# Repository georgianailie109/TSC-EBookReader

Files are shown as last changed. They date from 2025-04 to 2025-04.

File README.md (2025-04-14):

# TSC-EBookReader

## 1. Introducere si scop

OpenBook este un dispozitiv avansat construit in jurul microcontrolerului ESP32-C6, avand mai multi senzori si interfete. Acest dispozitiv este conceput pentru a oferi o experienta de citire electronica eficienta, cu un consum redus de energie si multiple functionalitati.

---

## 2. Diagrama bloc

```
        +------------------+
        |     Baterie      |
        +--------+---------+
                 |
                 v
        +--------------------+
        | Circuit Incarcare  |
        +--------+-----------+
                 |
                 v
        +--------------------+
        |        LDO         |
        +--------+-----------+
                 |
+----------------+---------------------------+
|                |           |              |
v                v           v              v
+--------+   +-----------+  +-----------+  +----------------+
| ESP32  |<->|  Display  |<->|  BME688  |<->| Butoane tactile|
|  -C6   |   | (SPI 4W)  |   | (I2C)    |   |   (GPIO + RC)  |
+--------+   +-----------+  +-----------+  +----------------+
     |             ^            ^                ^
     |             |            |                |
     v             |      Rezistente        Circuit RC
+-----------------------+  Pull-up         debounce
|     Conector USB-C    |
+-----------------------+
```

---

## 3. Imagini

Cateva imagini din proiect (plasate in folderul `Images/`):
exploded_view













---

## 4. BOM (Bill of Materials)

| Componenta | Link achizitie | Link datasheet |
|---|---|---|
| 112A-TAAR-R03 ATTEND | https://store.comet.srl.ro/Catalogue/Product/43497/ | https://www.snapeda.com/parts/112A-TAAR-R03/Attend/datasheet/ |
| BD5229G-TR | https://www.digikey.com/en/products/detail/rohm-semiconductor/BD5229G-TR/3663792 | https://fscdn.rohm.com/en/products/databook/datasheet/ic/power/voltage_detector/bd52xxg-e.pdf |
| ESP32 WROVER BME680 Sensor | https://store.comet.srl.ro/Catalogue/Product/50164/ | https://www.bosch-sensortec.com/media/boschsensortec/downloads/datasheets/bst-bme680-ds001.pdf |
| LED CHG_LED | https://ro.mouser.com/ProductDetail/Kingbright/KP-1608SURCK?qs=2JU0tDl2GZ3FuyEWfBV1%2Fg== | https://www.snapeda.com/parts/KP-1608SURCK/Kingbright/datasheet/ |
| Condensator C0402 | https://ro.mouser.com/c/passive-components/capacitors/ceramic-capacitors/?q=CC0402 | https://componentsearchengine.com/Datasheets/2/CC0402MRX5R5BB106.pdf |
| Condensator Tant | https://ro.mouser.com/ProductDetail/KYOCERA-AVX/TAJW107M010RNJ?qs=Wtp%252Bf%2FAeVqIH8v1VxV%252B1Rg%3D%3D | https://ro.mouser.com/datasheet/2/40/TAJ-3165264.pdf |
| Q1 DMG2305UX-7 | https://www.digikey.com/en/products/detail/diodes-incorporated/DMG2305UX-7/4340666 | https://www.diodes.com/assets/Datasheets/DMG2305UX.pdf |
| RTC MODULE DS3231SN# | https://www.snapeda.com/parts/DS3231SN%23/Analog+Devices/view-part/?ref=eda | https://www.snapeda.com/parts/DS3231SN%23/Analog%20Devices/datasheet/ |
| ESP32 C6 WROOM-1-N8 | https://ro.mouser.com/ProductDetail/Espressif-Systems/ESP32-C6-WROOM-1-N8?qs=8Wlm6%252BaMh8ST02Gmwp74cw%3D%3D | https://www.snapeda.com/parts/ESP32-C6-WROOM-1-N8/Espressif%20Systems/datasheet/ |
| FH34SRJ-24S-0.5SH(99) | https://ro.mouser.com/ProductDetail/Hirose-Connector/FH34SRJ-24S-0.5SH99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 | https://www.snapeda.com/parts/FH34SRJ-24S-0.5SH(99)/Hirose%20Connector/datasheet/ |
| MAX 17048G+T10 | https://www.snapeda.com/parts/MAX17048G+T10/Analog+Devices/view-part/?ref=eda | https://www.snapeda.com/parts/MAX17048G+T10/Analog%20Devices/datasheet/ |
| MBR0530 Schottky Diode | https://www.snapeda.com/parts/MBR0530/Onsemi/view-part/?ref=snap | https://www.snapeda.com/parts/MBR0530/ON%20Semiconductor/datasheet/ |
| MCP73831 Power Management | https://www.snapeda.com/parts/MCP73831T-2ACI/OT/Microchip/datasheet/ | https://www.snapeda.com/parts/MCP73831T-2ACI/OT/Microchip/datasheet/ |
| PFMF.050.1 | https://ro.mouser.com/ProductDetail/EPCOS-TDK/B72520T0350K062?qs=dEfas%2FXlABIszF52uu7vrg%3D%3D | https://www.tdk-electronics.tdk.com/inf/75/db/CTVS_14/Surge_protection_series.pdf |
| PGB1010603MR | https://www.snapeda.com/parts/PGB1010603MR/Littelfuse/view-part/?ref=eda | https://www.snapeda.com/parts/PGB1010603MR/Littelfuse%20Inc./datasheet/ |
| QWIIC_RIGHT_ANGLE CONNECTOR | https://ro.mouser.com/ProductDetail/SparkFun/PRT-14417?qs=wd5RIQLrsJhgdz%2FpmZ%2F3GQ== | https://ro.mouser.com/datasheet/2/813/Qwiic_Connector_Datasheet-1223982.pdf |
| Rezistenta R0402 | https://grabcad.com/library/resistor-0402-1) | https://www.yageo.com/upload/media/product/products/datasheet/rchip/PYu-RC_Group_51_RoHS_L_12.pdf |
| SD0805S020S1R0 | https://ro.mouser.com/ProductDetail/KYOCERA-AVX/SD0805S020S1R0?qs=jCA%252BPfw4LHbpkAoSnwrdjw%3D%3D | https://ro.mouser.com/datasheet/2/40/schottky-3165252.pdf |
| Si1308EDL-T1-GE3 MOSFET | https://www.snapeda.com/parts/SI1308EDL-T1-GE3/Vishay+Siliconix/view-part/?welcome=home&ref=eda | https://www.snapeda.com/parts/SI1308EDL-T1-GE3/Vishay%20Siliconix/datasheet/ |
| USB4110-GF-A | https://ro.mouser.com/ProductDetail/GCT/USB4110-GF-A?qs=KUoIvG%2F9IlYiZvIXQjyJeA%3D%3D | https://ro.mouser.com/datasheet/2/837/GCT_USB4110_Product_Drawing___20k_cycles-3455479.pdf |
| USBLC6-2SC6Y | https://ro.mouser.com/ProductDetail/STMicroelectronics/USBLC6-2SC6Y?qs=gNDSiZmRJS%2FOgDexvXkdow%3D%3D | https://ro.mouser.com/datasheet/2/389/usblc6_2sc6y-1852505.pdf |
| W25Q512JVEIQ | https://www.snapeda.com/parts/W25Q512JVEIQ/Winbond+Electronics/view-part/?ref=eda | https://www.winbond.com/resource-files/W25Q512JV%20SPI%20RevB%2006252019%20KMS.pdf |
| XC6220A331MR-G | https://componentsearchengine.com/part-view/XC6220A331MR-G/Torex | https://product.torexsemi.com/system/files/series/xc6220.pdf |
| 744043680 BOBINA | https://ro.mouser.com/ProductDetail/Wurth-Elektronik/744043680?qs=PGXP4M47uW6VkZq%252BkzjrHA%3D%3D | https://www.we-online.com/components/products/datasheet/744043680.pdf |

---

## 5. Functionalitatea hardware

- ESP32-C6 este componenta principala a proiectului OpenBook, oferind conectivitate Wi-Fi 6 si Bluetooth 5.0 LE. Datorita conectivitatii wireless integrate si a numarului mare de pini GPIO, microcontrollerul permite interfatarea cu diverse componente periferice, asigurand flexibilitate si performanta ridicata.
- Afisajul e-paper este conectat la ESP32-C6 prin interfata SPI si utilizeaza driver-ul BD5229G-TR pentru a gestiona tensiunile necesare functionarii. Alimentarea afisajului este controlata prin MOSFET-uri, permitand oprirea completa a acestuia atunci cand nu este utilizat, ceea ce contribuie la eficienta energetica a dispozitivului.
- Pentru monitorizarea conditiilor de mediu, proiectul utilizeaza senzorul BME688, capabil sa masoare temperatura, umiditatea, presiunea si calitatea aerului (VOC). Acesta comunica cu ESP32-C6 prin intermediul interfetei I2C si functioneaza la o tensiune de 3.3V, oferind date precise.
- Gestionarea energiei este realizata printr-un circuit de incarcare bazat pe MCP73831, care permite incarcarea bateriei cu un curent de pana la 500mA.
- Starea bateriei este monitorizata cu modulul MAX17048G+T10, care comunica prin aceeasi interfata I2C si furnizeaza informatii detaliate despre nivelul de incarcare si starea bateriei.

---

## 6. Alocarea pinilor ESP32-C6

| Componenta | Pini ESP32 | Interfata | Observatii |
|---|---|---|---|
| Afisaj E-Paper | IO12, IO11, IO5, IO4 | SPI | Control si resetare afisaj |
| Senzor BME688 | IO8, IO10 | I2C | Date de mediu (temperatura, umiditate) |
| Card SD | IO7 | SPI | Stocare externa |
| Modul RTC | IO8, IO10 | I2C | Ceas in timp real, partajeaza I2C |
| Serial USB | IO16, IO17 | UART | Programare si depanare |

---

## 7. Pasi de implementare

Proiectarea schemei electrice si conectarea componentelor la ESP32-C6
Realizarea layout-ului 2D si pozitionarea componentelor pe PCB
Rutarea traseelor pentru semnal si alimentare
Crearea planurilor de masa pe ambele straturi
Aplicarea regulilor pentru latimea traseelor si clearance
Pozitionarea strategica a conectorilor (ex: Qwiic, USB-C)
Adaugarea pad-urilor de test pentru depanare
Generarea modelului 3D si verificarea compatibilitatii mecanice

---

## 8. Informatii suplimentare relevante

- TP-urile au fost plasate in mod optim langa marginile placii si in apropierea componentelor esentiale pentru a permite acces facil la depanare si testare.
- Pentru diodele montate pe suprafata, dimensiunea initiala a pad-urilor era prea mica, ceea ce putea crea probleme la lipire. Dimensiunea a fost ajustata pentru a asigura o conexiune electrica fiabila si o asamblare mai usoara.
- Rutarea traseelor a fost realizata pe ambele straturi ale PCB-ului (superior si inferior), asigurand o distributie eficienta a semnalelor si a alimentarii.
- Planul de masa (GND) a fost aplicat pe ambele straturi pentru a optimiza performanta electrica.

---

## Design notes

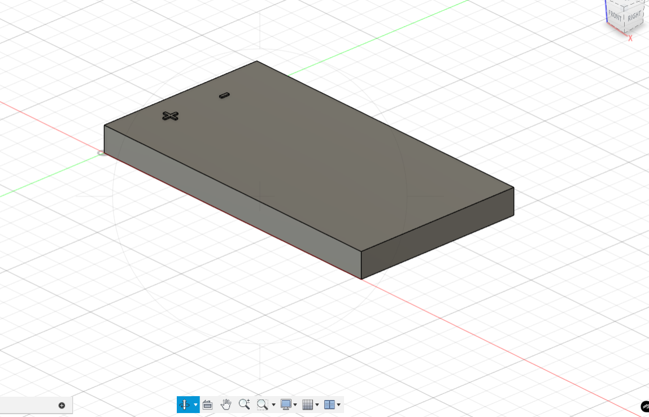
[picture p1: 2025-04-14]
Images/Screenshot 2025-04-14 140932.png

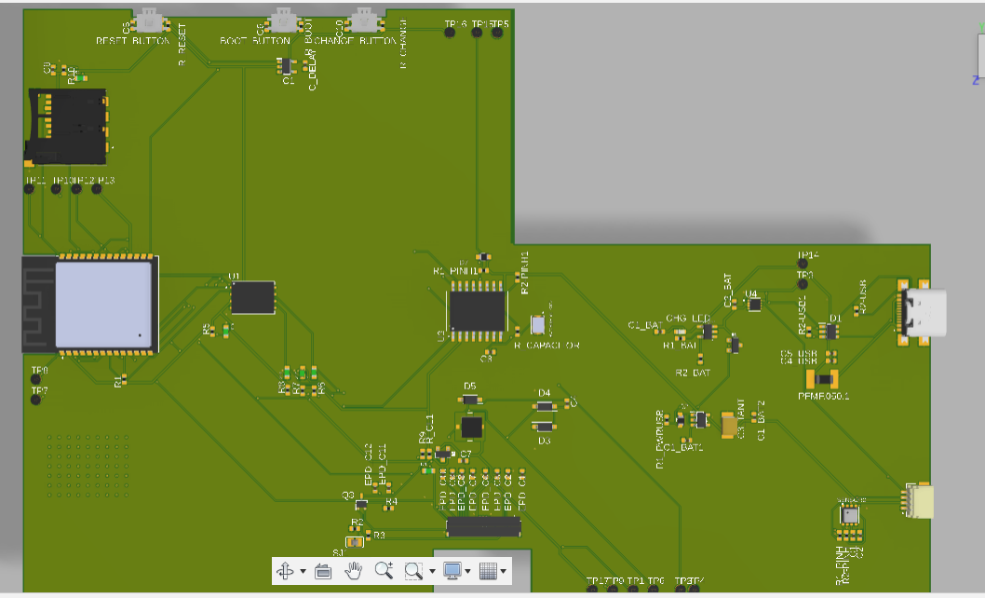
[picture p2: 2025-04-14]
Images/Screenshot 2025-04-14 141032.png

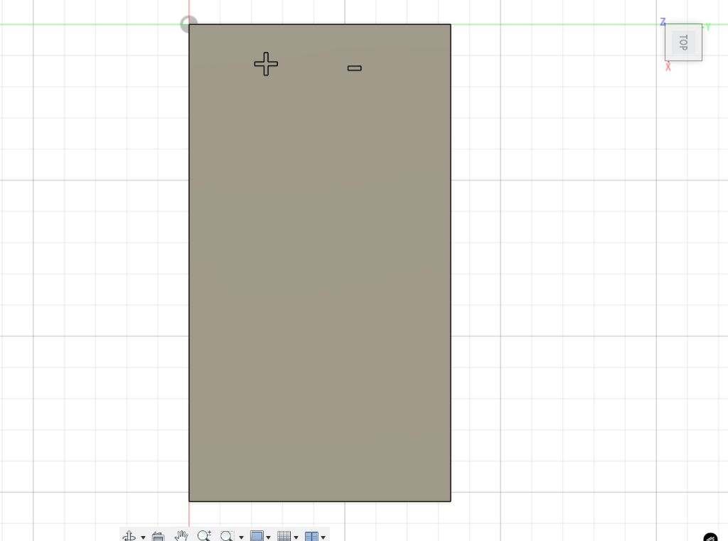
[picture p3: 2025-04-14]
Images/Screenshot 2025-04-14 140912.png

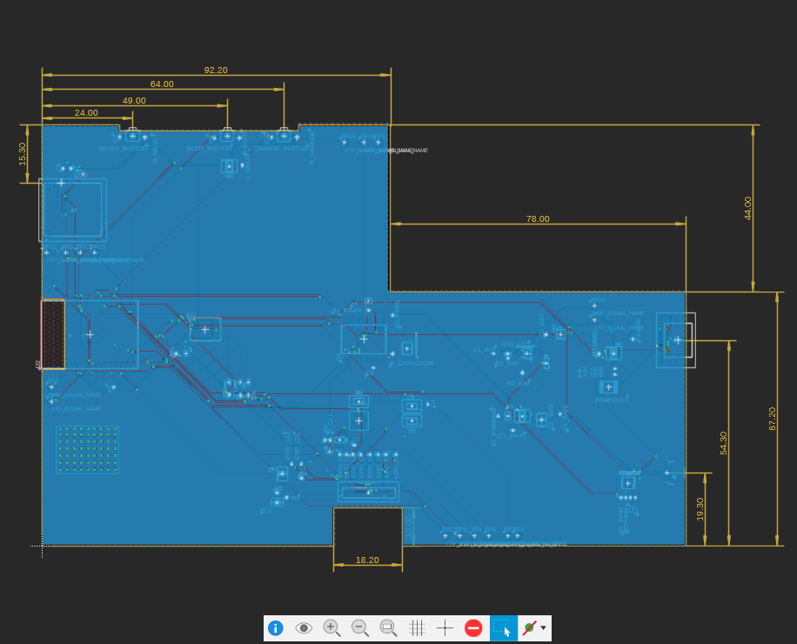
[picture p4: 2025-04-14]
Images/Screenshot 2025-04-14 141126.png

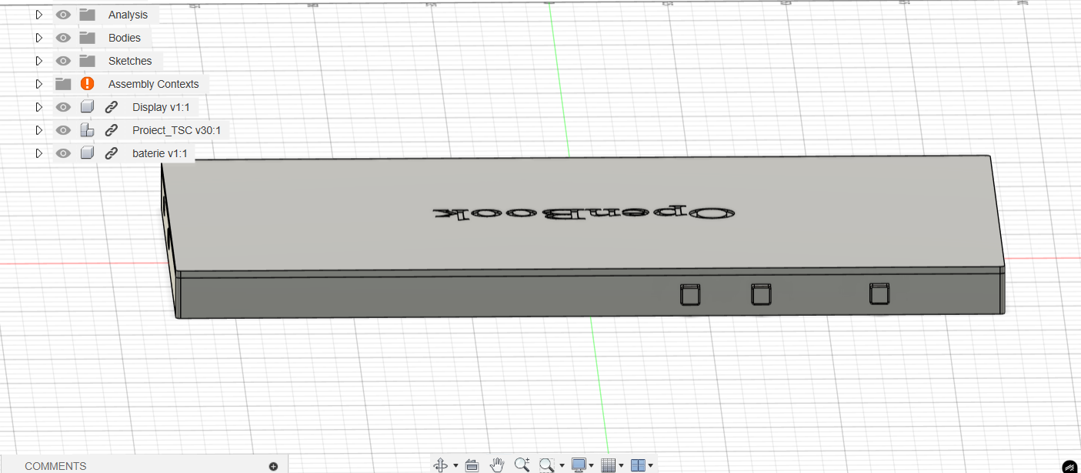
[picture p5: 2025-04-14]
Images/Screenshot 2025-04-14 140544.png

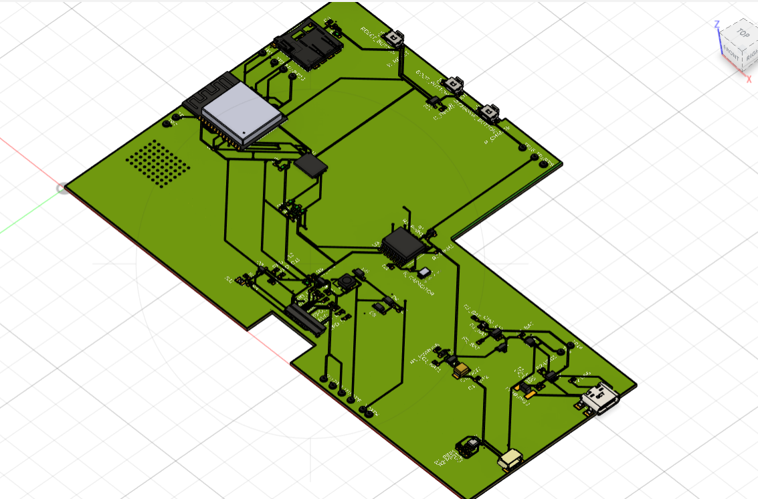
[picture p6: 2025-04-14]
Images/Screenshot 2025-04-14 141807.png

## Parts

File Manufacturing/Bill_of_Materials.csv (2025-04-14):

Qty | Value | Device | Package | Parts | Description | ARROW_PART_NUMBER | ARROW_PRICE-STOCK | AVAILABILITY | CENTROID_NOT_SPECIFIED | CHECK_PRICES | COPYRIGHT | DATASHEET | DESCRIPTION | DIGIKEY_DESCRIPTION | DIGIKEY_PART_NUMBER | HEIGHT | LEAD_FREE | MANUFACTURER_NAME | MANUFACTURER_PART_NUMBER | MF | MFR_NAME | MOUSER_PART_NUMBER | MOUSER_PRICE-STOCK | MOUSER_TESTING_PART_NUMBER | MOUSER_TESTING_PRICE-STOCK | MP | MPN | PACKAGE | POPULARITY | PREFIX | PRICE | PROD_ID | PURCHASE-URL | ROHS | SNAPEDA_LINK | SPICEMODEL | SPICEPREFIX | TEMPERATURE_RANGE_HIGH | TEMPERATURE_RANGE_LOW | VALUE
1 |  | ADAFRUIT_LEDCHIP-LED0603 | ADAFRUIT_CHIP-LED0603 | CHG_LED | LED
1 |  | SJ | SJ | SJ1 | SMD solder JUMPER |  |  |  |  |  |  |  |  |  |  |  |  |  |  |  |  |  |  |  |  |  |  |  | 3
1 | 0.1uF/50V | EAGLE-LTSPICE_CC0402 | EAGLE-LTSPICE_C0402 | EPD_C5 | CAPACITOR, European symbol
1 | 0.47 | ESP32_WROVER_EAGLE-LTSPICE_RR0402 | ESP32_WROVER_EAGLE-LTSPICE_R0402 | R3 | RESISTOR, European symbol
1 | 100 nF | ESP32_WROVER_EAGLE-LTSPICE_CC0402 | ESP32_WROVER_EAGLE-LTSPICE_C0402 | C4_USB | CAPACITOR, European symbol |  |  |  |  |  |  |  |  |  |  |  |  |  |  |  |  |  |  |  |  |  |  |  |  |  |  |  |  |  |  | NONE | C
1 | 100k | ESP32_WROVER_EAGLE-LTSPICE_RR0402 | ESP32_WROVER_EAGLE-LTSPICE_R0402 | R1_PWRUSB | RESISTOR, European symbol
7 | 100nF | EAGLE-LTSPICE_CC0402 | EAGLE-LTSPICE_C0402 | C1, C2, C6, C8, C9, C10, C_DELAY | CAPACITOR, European symbol
1 | 100uF | RCL_CPOL-EUCT3528 | RCL_CT3528 | C3_TANT | POLARIZED CAPACITOR, European symbol |  |  |  |  |  |  |  |  |  |  |  |  |  |  |  |  |  |  |  |  |  |  |  | 0 |  |  |  |  |  |  |  | C
10 | 10K | ESP32_WROVER_EAGLE-LTSPICE_RR0402 | ESP32_WROVER_EAGLE-LTSPICE_R0402 | R1_PINH, R1_PINH1, R2-PINH, R2-PINH1, R5, R6, R7, R8, R9, R10 | RESISTOR, European symbol
6 | 10k | ESP32_WROVER_EAGLE-LTSPICE_RR0402 | ESP32_WROVER_EAGLE-LTSPICE_R0402 | R1, R4, R_BOOT, R_CHANGE, R_CL1, R_RESET | RESISTOR, European symbol
1 | 10uF | EAGLE-LTSPICE_CC0402 | EAGLE-LTSPICE_C0402 | C7 | CAPACITOR, European symbol
1 | 112A-TAAR-R03_ATTEND | 112A-TAAR-R03_ATTEND | 112ATAARR03ATTEND | J4 | Micro SD Card Socket, Push-Push Type, Top Mount, SMT, H=1.83mm, 10u |  |  |  |  |  |  |  | Micro SD Card Socket | Push-Push Type | Top Mount | SMT | H=1.83mm | 10u |  |  | 1.9mm |  | ATTEND | 112A-TAAR-R03 ATTEND
1 | 15 | ESP32_WROVER_EAGLE-LTSPICE_RR0402 | ESP32_WROVER_EAGLE-LTSPICE_R0402 | R_CAPACITOR | RESISTOR, European symbol
1 | 1uF | EAGLE-LTSPICE_CC0402 | EAGLE-LTSPICE_C0402 | C5 | CAPACITOR, European symbol
9 | 1uF/50V | EAGLE-LTSPICE_CC0402 | EAGLE-LTSPICE_C0402 | EPD_C1, EPD_C2, EPD_C6, EPD_C7, EPD_C8, EPD_C9, EPD_C10, EPD_C11, EPD_C12 | CAPACITOR, European symbol
1 | 2.2 | ESP32_WROVER_EAGLE-LTSPICE_RR0402 | ESP32_WROVER_EAGLE-LTSPICE_R0402 | R2 | RESISTOR, European symbol
1 | 200 | ESP32_WROVER_EAGLE-LTSPICE_RR0402 | ESP32_WROVER_EAGLE-LTSPICE_R0402 | R1_BAT | RESISTOR, European symbol
2 | 20V/4.2A/52mO/1.4W | ESP32_WROVER_SPARKFUN-DISCRETESEMI_MOSFET_PCH-DMG2305UX-7 | ESP32_WROVER_SPARKFUN-DISCRETESEMI_SOT23-3 | Q1, Q2 | P-channel MOSFETs |  |  |  |  |  |  |  |  |  |  |  |  |  |  |  |  |  |  |  |  |  |  |  |  |  |  | TRAN-14388 |  |  |  |  |  |  |  | 20V/4.2A/52mO/1.4W
1 | 2k | ESP32_WROVER_EAGLE-LTSPICE_RR0402 | ESP32_WROVER_EAGLE-LTSPICE_R0402 | R2_BAT | RESISTOR, European symbol
1 | 4.5uF | ESP32_WROVER_EAGLE-LTSPICE_CC0402 | ESP32_WROVER_EAGLE-LTSPICE_C0402 | C5_USB | CAPACITOR, European symbol |  |  |  |  |  |  |  |  |  |  |  |  |  |  |  |  |  |  |  |  |  |  |  |  |  |  |  |  |  |  | NONE | C
2 | 4.7uF | EAGLE-LTSPICE_CC0402 | EAGLE-LTSPICE_C0402 | C1_BAT, C2_BAT | CAPACITOR, European symbol
2 | 4.7uF | ESP32_WROVER_EAGLE-LTSPICE_CC0402 | ESP32_WROVER_EAGLE-LTSPICE_C0402 | C1_BAT1, C1_BAT2 | CAPACITOR, European symbol |  |  |  |  |  |  |  |  |  |  |  |  |  |  |  |  |  |  |  |  |  |  |  |  |  |  |  |  |  |  | NONE | C
1 | 4.7uF/25V | EAGLE-LTSPICE_CC0402 | EAGLE-LTSPICE_C0402 | C4 | CAPACITOR, European symbol
2 | 5k1 | ESP32_WROVER_EAGLE-LTSPICE_RR0402 | ESP32_WROVER_EAGLE-LTSPICE_R0402 | R2-USB, R2-USB1 | RESISTOR, European symbol
1 | 68uH | 744043680IND_4828-WE-TPC_WRE | IND_4828-WE-TPC_WRE | L1 |  |  |  |  |  |  | Copyright (C) 2024 Ultra Librarian. All rights reserved. |  |  |  |  |  |  |  | 744043680 |  | Wurth Electronics
1 | BD5229G-TR | BD5229G-TR | SOT95P280X125-5N | IC1 | Voltage Detector with Adjustable Delay Time: CMOS processes are utilized to develop high precision, low current consumption CMOS reset ICs that allow arbitrary setting of the delay time. The extensive lineup includes both Nch Open Drain and CMOS output types in a wide range of detection voltages (from 2.3V to 6.0V, in 0.1V steps), enabling selection of the ideal solution based on customer requirements. In addition, the entire series is of course both lead-free and RoHS-compliant. |  |  |  |  |  |  |  | Voltage Detector with Adjustable Delay Time: CMOS processes are utilized to develop high precision | low current consumption CMOS reset ICs that allow arbitrary setting of the delay time. The extensive lineup includes both Nch Open Drain and CMOS output types in a wide range of detection voltages (from 2.3V to 6.0V | in 0.1V steps) | enabling selection of the ideal solution based on customer requirements. In addition | the entire series is of course both lead-free and RoHS-compliant. |  |  | 1.25mm |  | ROHM Semiconductor | BD5229G-TR |  |  | 755-BD5229G-TR | https://www.mouser.co.uk/ProductDetail/ROHM-Semiconductor/BD5229G-TR?qs=4kLU8WoGk0vvnhrrYwdszw%3D%3D
3 | BUTTON_CUSYOMV1 | BUTTON_CUSYOMV1 | MYBUTTON | BOOT_BUTTON, CHANGE_BUTTON, RESET_BUTTON
1 | CPH3225A | CPH3225A | CAPCP3225X100N | C10_SUPERCAP | Cap 0.011F 3.3V 1210 Flat Check availability |  |  | Not in stock |  | https://www.snapeda.com/parts/CPH3225A/Seiko+Instruments/view-part/?ref=eda |  |  | 11 mF (EDLC) Supercapacitor 3.3 V 1210 (3225 Metric) - - |  |  |  |  |  |  | Seiko Instruments |  |  |  |  |  | CPH3225A |  | 1210 Seiko |  |  | None |  | https://www.snapeda.com/api/url_track_click_mouser/?unipart_id=562593&manufacturer=Seiko Instruments&part_name=CPH3225A&search_term=None |  | https://www.snapeda.com/parts/CPH3225A/Seiko+Instruments/view-part/?ref=snap
1 | DS3231SN# | DS3231SN# | SOIC127P1032X265-16N | U3 | Real Time Clock Serial 16-Pin SOIC W T/R Check availability |  |  | In Stock |  | https://www.snapeda.com/parts/DS3231SN%23/Analog+Devices/view-part/?ref=eda |  |  | Extremely Accurate I²C-Integrated RTC/TCXO/Crystal |  |  |  |  |  |  | Analog Devices |  |  |  |  |  | DS3231SN# |  | SOIC-16 Maxim |  |  | None |  | https://www.snapeda.com/api/url_track_click_mouser/?unipart_id=99048&manufacturer=Analog Devices&part_name=DS3231SN#&search_term=None |  | https://www.snapeda.com/parts/DS3231SN%23/Analog+Devices/view-part/?ref=snap
1 | ESP32-C6-WROOM-1-N8 | ESP32-C6-WROOM-1-N8 | XCVR_ESP32-C6-WROOM-1-N8 | U2 | Check availability |  |  | In Stock |  | https://www.snapeda.com/parts/ESP32-C6-WROOM-1-N8/Espressif+Systems/view-part/?ref=eda |  |  | Multiprotocol Modules ESP32-C6 module | Wi-Fi 6 in 2.4 GHz band | Bluetooth 5 | Zigbee 3.0 and Thread. ESP34-WROOM Compatible - ENGINEERING SAMPLE |  |  |  |  |  |  | Espressif Systems |  |  |  |  |  | ESP32-C6-WROOM-1-N8 |  | None |  |  | None |  |  |  | https://www.snapeda.com/parts/ESP32-C6-WROOM-1-N8/Espressif+Systems/view-part/?ref=snap
1 | ESP32C6_VARISTORCN1812 | ESP32C6_VARISTORCN1812 | ESP32C6_VARISTOR_CT/CN1812 | PFMF.050.1 | VARISTOR |  |  |  |  |  |  |  |  |  |  |  |  |  |  |  |  |  |  |  |  |  |  |  | 0
2 | ESP32_WROVER_AVX---SD0805S020S1R0_AVX_SD0805S020S1R0_0_0AVX_SD0805S020S1R0_0_0 | ESP32_WROVER_AVX---SD0805S020S1R0_AVX_SD0805S020S1R0_0_0AVX_SD0805S020S1R0_0_0 | ESP32_WROVER_AVX---SD0805S020S1R0_AVX_SD0805S020S1R0_0 | D2, D7 | Schottky Barrier Rectifier Diode |  |  |  | No |  |  | http://datasheets.avx.com/schottky.pdf |  | DIODE SCHOTTKY 20V 1A 0805 | 478-7800-1-ND |  | yes |  |  | AVX |  | 581-SD0805S020S1R0 |  |  |  |  |  | 0805 (2012 metric) |  | D |  |  |  | yes |  |  |  | +125°C | -55°C
1 | ESP32_WROVER_BME680_BME680 | ESP32_WROVER_BME680_BME680 | ESP32_WROVER_BME680_PSON80P300X300X100-8N | SENSOR2 | Integrated Environmental Unit |  |  | Unavailable |  |  |  |  | Integrated Environmental Unit |  |  |  |  |  |  | Bosch Sensortec |  |  |  |  |  | BME680 |  | LGA-8 Bosch Tools |  |  | None
1 | ESP32_WROVER_SPARKFUN-IC-POWER_MCP73831 | ESP32_WROVER_SPARKFUN-IC-POWER_MCP73831 | ESP32_WROVER_SPARKFUN-IC-POWER_SOT23-5 | MCP73831 | MCP73831T Li-Ion, Li-Pol Controller |  |  |  |  |  |  |  |  |  |  |  |  |  |  |  |  |  |  |  |  |  |  |  |  |  |  | IC-09995
1 | FH34SRJ-24S-0.5SH_99_ | FH34SRJ-24S-0.5SH_99_ | FH34SRJ24S05SH99 | J1 | (0.50mm) Surface Mount, Right Angle |  |  |  |  |  |  |  | 24 Position FFC | FPC Connector Contacts | (0.50mm) Surface Mount | Right Angle |  |  | 1.1mm |  | Hirose | FH34SRJ-24S-0.5SH(99) |  |  | 798-FH34SRJ24S05SH99 | https://www.mouser.co.uk/ProductDetail/Hirose-Connector/FH34SRJ-24S-0.5SH99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
1 | MAX17048G+T10 | MAX17048G+T10 | SON50P200X200X80-9N | U4 | Check availability |  |  | In Stock |  | https://www.snapeda.com/parts/MAX17048G+T10/Analog+Devices/view-part/?ref=eda |  |  | 3µA 1-Cell/2-Cell Fuel Gauge with ModelGauge |  |  |  |  |  |  | Analog Devices |  |  |  |  |  | MAX17048G+T10 |  | TDFN-8 Maxim |  |  | None |  | https://www.snapeda.com/api/url_track_click_mouser/?unipart_id=329239&manufacturer=Analog Devices&part_name=MAX17048G+T10&search_term=None |  | https://www.snapeda.com/parts/MAX17048G+T10/Analog+Devices/view-part/?ref=snap
3 | MBR0530 | MBR0530 | SOD3716X135N | D3, D4, D5 | ON SEMICONDUCTOR - MBR0530 - DIODE, SCHOTTKY, 0.5A, 30V, SOD-123 |  |  | In Stock |  | https://www.snapeda.com/parts/MBR0530/Onsemi/view-part/?ref=eda |  |  | Diode Schottky 30 V 500mA Surface Mount SOD-123 |  |  |  |  |  |  | ON Semiconductor |  |  |  |  |  | MBR0530 |  | SOD-123-2 ON Semiconductor |  |  | None |  | https://www.snapeda.com/api/url_track_click_mouser/?unipart_id=179458&manufacturer=ON Semiconductor&part_name=MBR0530&search_term=None |  | https://www.snapeda.com/parts/MBR0530/Onsemi/view-part/?ref=snap
6 | PGB1010603MR | PGB1010603MR | DIOC1608X36N | D6, D8, D9, D10, D11, D12 | Check availability |  |  | In Stock |  | https://www.snapeda.com/parts/PGB1010603MR/Littelfuse/view-part/?ref=eda |  |  | 150V (Typ) Clamp - Ipp Tvs Diode Surface Mount 0603 (1608 Metric) |  |  |  |  |  |  | Littelfuse Inc. |  |  |  |  |  | PGB1010603MR |  | 0603 Littelfuse Inc. |  |  | None |  | https://www.snapeda.com/api/url_track_click_mouser/?unipart_id=5659453&manufacturer=Littelfuse Inc.&part_name=PGB1010603MR&search_term=None |  | https://www.snapeda.com/parts/PGB1010603MR/Littelfuse/view-part/?ref=snap
1 | QWIIC_RIGHT_ANGLE | QWIIC_CONNECTORJS-1MM | JST04_1MM_RA | J3 | SparkFun I2C Standard Qwiic Connector |  |  |  |  |  |  |  |  |  |  |  |  |  |  |  |  |  |  |  |  |  |  |  |  |  |  | CONN-13694 |  |  |  |  |  |  |  | QWIIC_RIGHT_ANGLE
1 | SAMACSYS_PARTS_USB4110-GF-A | SAMACSYS_PARTS_USB4110-GF-A | SAMACSYS_PARTS_USB4110GFA | J2 | CONN USB 2.0 TYPE-C R/A SMT |  |  |  |  |  |  |  | CONN USB 2.0 TYPE-C R/A SMT |  |  | 3.26mm |  | GCT (GLOBAL CONNECTOR TECHNOLOGY) | USB4110-GF-A |  |  | 640-USB4110-GF-A | https://www.mouser.co.uk/ProductDetail/GCT/USB4110-GF-A?qs=KUoIvG%2F9IlYiZvIXQjyJeA%3D%3D
1 | SI1308EDL-T1-GE3 | SI1308EDL-T1-GE3 | SOT65P210X110-3N | Q3 | MOSFET N-Ch 30V 1.5A TrenchFET SC70 Vishay Si1308EDL-T1-GE3 N-channel MOSFET Transistor, 1.5 A, 30 V, 3-Pin SC-70 |  |  | In Stock |  | https://www.snapeda.com/parts/SI1308EDL-T1-GE3/Vishay+Siliconix/view-part/?ref=eda |  |  | Si1308EDL-T1-GE3 N-channel MOSFET Transistor | 1.5 A | 30 V | 3-Pin SC-70 | Siliconix / Vishay SI1308EDL-T1-GE3 |  |  |  |  |  |  | Vishay Siliconix |  |  |  |  |  | SI1308EDL-T1-GE3 |  | SOT-323 Vishay Semiconductor |  |  | None |  | https://www.snapeda.com/api/url_track_click_mouser/?unipart_id=274603&manufacturer=Vishay Siliconix&part_name=SI1308EDL-T1-GE3&search_term=None |  | https://www.snapeda.com/parts/SI1308EDL-T1-GE3/Vishay+Siliconix/view-part/?ref=snap
17 | TPTP20R | TPTP20R | TP20R | TP1, TP2, TP3, TP4, TP5, TP6, TP7, TP8, TP9, TP10, TP11, TP12, TP13, TP14, TP15, TP16, TP17 | Test pad
1 | USBLC6-2SC6Y | USBLC6-2SC6Y | SOT95P280X145-6N | D1 | Low Cap. ESD Protection Auto SOT-23-6 STMicroelectronics USBLC6-2SC6Y, Dual Uni-Directional TVS Diode Array, 6-Pin SOT-23 |  |  | In Stock |  | https://www.snapeda.com/parts/USBLC6-2SC6Y/STMicroelectronics/view-part/?ref=eda |  |  | 17V Clamp 5A (8/20µs) Ipp Tvs Diode Surface Mount SOT-23-6 |  |  |  |  |  |  | STMicroelectronics |  |  |  |  |  | USBLC6-2SC6Y |  | SOT-23-6 STMicroelectronics |  |  | None |  |  |  | https://www.snapeda.com/parts/USBLC6-2SC6Y/STMicroelectronics/view-part/?ref=snap
1 | W25Q512JVEIQ | W25Q512JVEIQ | SON127P600X800X80-9N | U1 | Check availability |  |  | In Stock |  | https://www.snapeda.com/parts/W25Q512JVEIQ/Winbond+Electronics/view-part/?ref=eda |  |  | FLASH - NOR Memory IC 512Mb (64M x 8) SPI - Quad I/O 133 MHz 8-WSON (8x6) |  |  |  |  |  |  | Winbond Electronics |  |  |  |  |  | W25Q512JVEIQ |  | Package |  |  | None |  |  |  | https://www.snapeda.com/parts/W25Q512JVEIQ/Winbond+Electronics/view-part/?ref=snap
1 | XC6220A331MR-G | XC6220A331MR-G | SOT95P280X120-5N | IC4 | LDO Voltage Regulators |  |  |  |  |  |  |  | LDO Voltage Regulators |  |  | 1.2mm |  | Torex | XC6220A331MR-G |  |  | 865-XC6220A331MR-G | https://www.mouser.co.uk/ProductDetail/Torex-Semiconductor/XC6220A331MR-G?qs=AsjdqWjXhJ8ZSWznL1J0gg%3D%3D

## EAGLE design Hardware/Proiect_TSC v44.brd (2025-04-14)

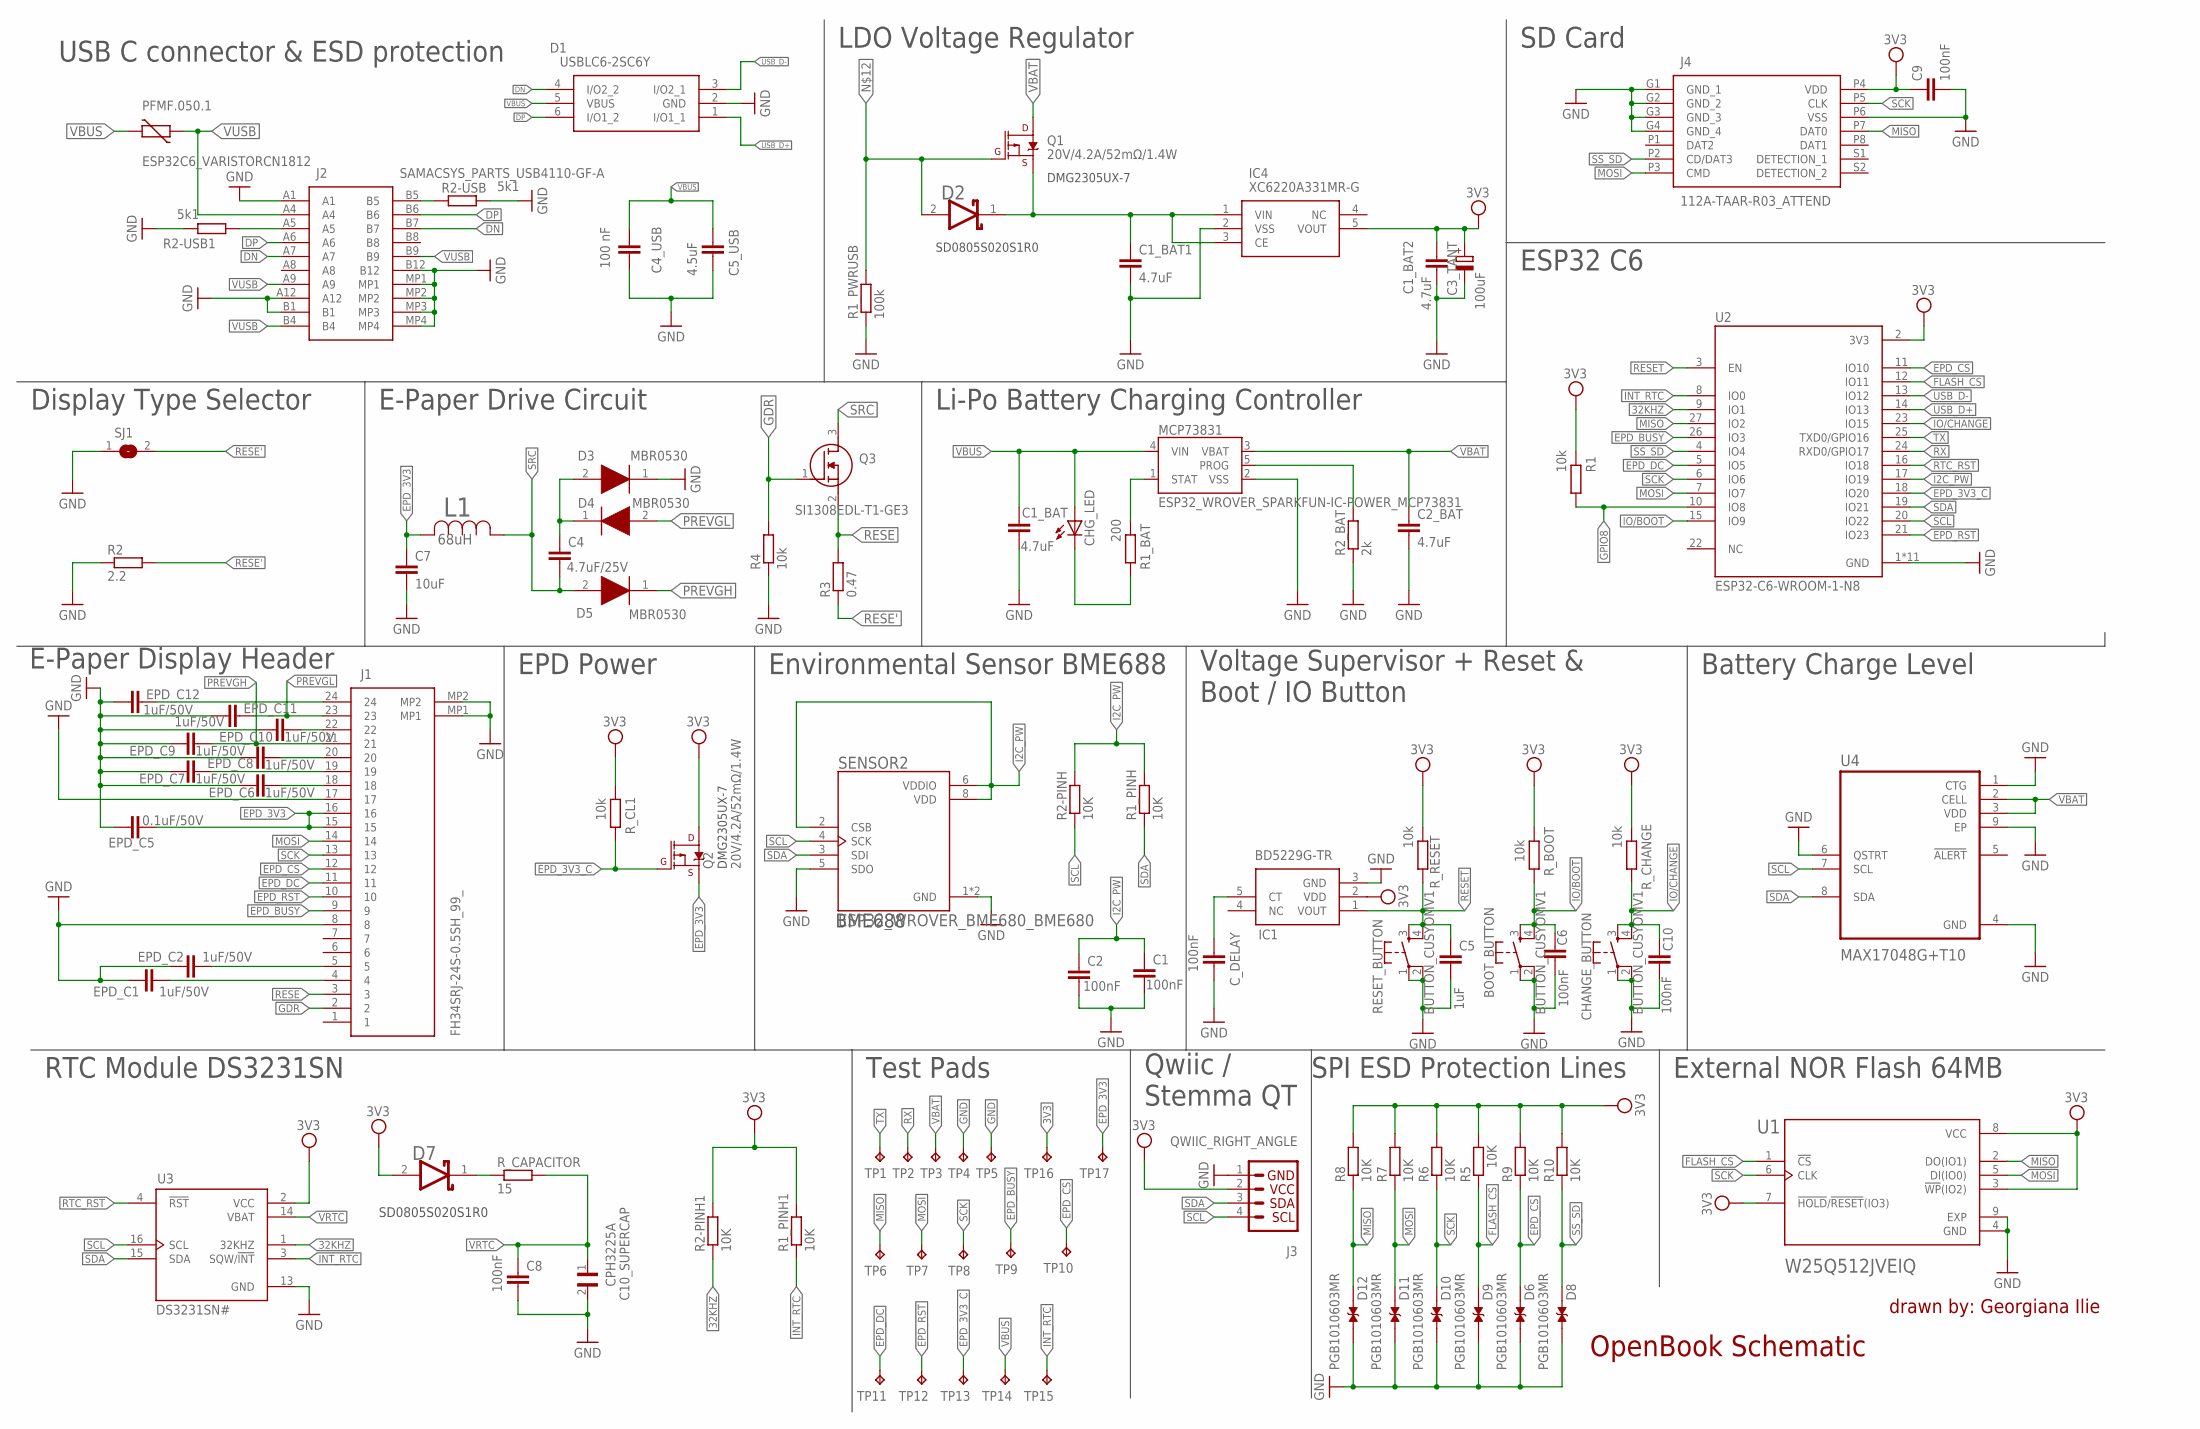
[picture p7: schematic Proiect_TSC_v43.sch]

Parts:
BOOT_BUTTON: BUTTON_CUSYOMV1; MYBUTTON
C1, C2, C6, C8, C9, C10: 100nF; EAGLE-LTSPICE_C0402
C1_BAT, C2_BAT: 4.7uF; EAGLE-LTSPICE_C0402
C1_BAT1, C1_BAT2: 4.7uF; ESP32_WROVER_EAGLE-LTSPICE_C0402
C3_TANT: 100uF; RCL_CT3528
C4: 4.7uF/25V; EAGLE-LTSPICE_C0402
C4_USB: 100 nF; ESP32_WROVER_EAGLE-LTSPICE_C0402
C5: 1uF; EAGLE-LTSPICE_C0402
C5_USB: 4.5uF; ESP32_WROVER_EAGLE-LTSPICE_C0402
C7: 10uF; EAGLE-LTSPICE_C0402
C10_SUPERCAP: CPH3225A; CAPCP3225X100N
CHANGE_BUTTON: BUTTON_CUSYOMV1; MYBUTTON
CHG_LED: ADAFRUIT_LEDCHIP-LED0603; ADAFRUIT_CHIP-LED0603
C_DELAY: 100nF; EAGLE-LTSPICE_C0402
D1: USBLC6-2SC6Y; SOT95P280X145-6N
D2, D7: ESP32_WROVER_AVX---SD0805S020S1R0_AVX_SD0805S020S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; ESP32_WROVER_AVX---SD0805S020S1R0_AVX_SD0805S020S1R0_0
D3, D4, D5: MBR0530; SOD3716X135N
D6, D8, D9, D10, D11, D12: PGB1010603MR; DIOC1608X36N
EPD_C1, EPD_C2, EPD_C6, EPD_C7, EPD_C8, EPD_C9, EPD_C10, EPD_C11, EPD_C12: 1uF/50V; EAGLE-LTSPICE_C0402
EPD_C5: 0.1uF/50V; EAGLE-LTSPICE_C0402
IC1: BD5229G-TR; SOT95P280X125-5N
IC4: XC6220A331MR-G; SOT95P280X120-5N
J1: FH34SRJ-24S-0.5SH_99_; FH34SRJ24S05SH99
J2: SAMACSYS_PARTS_USB4110-GF-A; SAMACSYS_PARTS_USB4110GFA
J3: QWIIC_RIGHT_ANGLE; JST04_1MM_RA
J4: 112A-TAAR-R03_ATTEND; 112ATAARR03ATTEND
L1: 68uH; IND_4828-WE-TPC_WRE
MCP73831: ESP32_WROVER_SPARKFUN-IC-POWER_MCP73831; ESP32_WROVER_SPARKFUN-IC-POWER_SOT23-5
PFMF.050.1: ESP32C6_VARISTORCN1812; ESP32C6_VARISTOR_CT/CN1812
Q1, Q2: 20V/4.2A/52mΩ/1.4W; ESP32_WROVER_SPARKFUN-DISCRETESEMI_SOT23-3
Q3: SI1308EDL-T1-GE3; SOT65P210X110-3N
R1, R4: 10k; ESP32_WROVER_EAGLE-LTSPICE_R0402
R1_BAT: 200; ESP32_WROVER_EAGLE-LTSPICE_R0402
R1_PINH, R1_PINH1, R2-PINH, R2-PINH1, R5, R6, R7, R8, R9, R10: 10K; ESP32_WROVER_EAGLE-LTSPICE_R0402
R1_PWRUSB: 100k; ESP32_WROVER_EAGLE-LTSPICE_R0402
R2: 2.2; ESP32_WROVER_EAGLE-LTSPICE_R0402
R2-USB, R2-USB1: 5k1; ESP32_WROVER_EAGLE-LTSPICE_R0402
R2_BAT: 2k; ESP32_WROVER_EAGLE-LTSPICE_R0402
R3: 0.47; ESP32_WROVER_EAGLE-LTSPICE_R0402
RESET_BUTTON: BUTTON_CUSYOMV1; MYBUTTON
R_BOOT: 10k; ESP32_WROVER_EAGLE-LTSPICE_R0402
R_CAPACITOR: 15; ESP32_WROVER_EAGLE-LTSPICE_R0402
R_CHANGE: 10k; ESP32_WROVER_EAGLE-LTSPICE_R0402
R_CL1: 10k; ESP32_WROVER_EAGLE-LTSPICE_R0402
R_RESET: 10k; ESP32_WROVER_EAGLE-LTSPICE_R0402
SENSOR2: ESP32_WROVER_BME680_BME680; ESP32_WROVER_BME680_PSON80P300X300X100-8N
SJ1: SJ
TP1, TP2, TP3, TP4, TP5, TP6, TP7, TP8, TP9, TP10, TP11, TP12, TP13, TP14, TP15, TP16, TP17: TPTP20R; TP20R
U1: W25Q512JVEIQ; SON127P600X800X80-9N
U2: ESP32-C6-WROOM-1-N8; XCVR_ESP32-C6-WROOM-1-N8
U3: DS3231SN#; SOIC127P1032X265-16N
U4: MAX17048G+T10; SON50P200X200X80-9N

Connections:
3V3: C1_BAT2.1, C3_TANT.+, C9.1, D7.2 (ANODE), IC1.2 (VDD), IC4.5 (VOUT), J3.2, J4.P4 (VDD), Q2.3 (D), R1.2, R1_PINH1.2, R2-PINH1.2, R5.2, R6.2, R7.2, R8.2, R9.2, R10.2, R_BOOT.2, R_CHANGE.2, R_CL1.2, R_RESET.2, TP16.TP, U1.3 (!WP!(IO2)), U1.7 (!HOLD!/!RESET!(IO3)), U1.8 (VCC), U2.2 (3V3), U3.2 (VCC)
32KHZ: R2-PINH1.1, U2.9 (IO1), U3.1 (32KHZ)
DN: D1.4 (I/O2_2), J2.A7, J2.B7
DP: D1.6 (I/O1_2), J2.A6, J2.B6
EPD_3V3: C7.1, EPD_C5.2, J1.15, J1.16, L1.2, Q2.2 (S), TP17.TP
EPD_3V3_C: Q2.1 (G), R_CL1.1, TP13.TP, U2.18 (IO20)
EPD_BUSY: J1.9, TP9.TP, U2.26 (IO3)
EPD_CS: D6.2, J1.12, R9.1, TP10.TP, U2.11 (IO10)
EPD_DC: J1.11, TP11.TP, U2.5 (IO5)
EPD_RST: J1.10, TP12.TP, U2.21 (IO23)
FLASH_CS: D9.2, R5.1, U1.1 (!CS), U2.12 (IO11)
GDR: J1.2, Q3.1 (G), R4.2
GND: BOOT_BUTTON.1, BOOT_BUTTON.2, C1.2, C1_BAT.2, C1_BAT1.2, C1_BAT2.2, C2.2, C2_BAT.2, C3_TANT.-, C4_USB.2, C5.2, C5_USB.2, C6.2, C7.2, C8.2, C9.2, C10.2, C10_SUPERCAP.2, CHANGE_BUTTON.1, CHANGE_BUTTON.2, C_DELAY.2, D1.2 (GND), D3.1 (K), D6.1, D8.1, D9.1, D10.1, D11.1, D12.1, EPD_C1.1, EPD_C2.1, EPD_C5.1, EPD_C6.1, EPD_C7.1, EPD_C8.1, EPD_C9.1, EPD_C10.1, EPD_C11.1, EPD_C12.1, IC1.3 (GND), IC4.2 (VSS), J1.8, J1.17, J1.MP1, J1.MP2, J2.A1, J2.A12, J2.B1, J2.B12, J2.MP1, J2.MP2, J2.MP3, J2.MP4, J3.1, J4.G1 (GND_1), J4.G2 (GND_2), J4.G3 (GND_3), J4.G4 (GND_4), J4.P6 (VSS), MCP73831.2 (VSS), R1_PWRUSB.1, R2.1, R2-USB.2, R2-USB1.1, R2_BAT.1, R4.1, RESET_BUTTON.1, RESET_BUTTON.2, SENSOR2.1 (GND), SENSOR2.5 (SDO), SENSOR2.7 (GND), SJ1.1, TP4.TP, TP5.TP, U1.4 (GND), U1.9 (EXP), U2.1 (GND), U2.28 (GND), U2.29_1 (GND), U2.29_2 (GND), U2.29_3 (GND), U2.29_4 (GND), U2.29_5 (GND), U2.29_6 (GND), U2.29_7 (GND), U2.29_8 (GND), U2.29_9 (GND), U3.13 (GND), U4.1 (CTG), U4.4 (GND), U4.6 (QSTRT), U4.9 (EP)
GPIO8: R1.1, U2.10 (IO8)
I2C_PW: C1.1, C2.1, R1_PINH.2, R2-PINH.2, SENSOR2.2 (CSB), SENSOR2.6 (VDDIO), SENSOR2.8 (VDD), U2.17 (IO19)
INT_RTC: R1_PINH1.1, TP15.TP, U2.8 (IO0), U3.3 (SQW/!INT)
IO/BOOT: BOOT_BUTTON.3, BOOT_BUTTON.4, C6.1, R_BOOT.1, U2.15 (IO9)
IO/CHANGE: C10.1, CHANGE_BUTTON.3, CHANGE_BUTTON.4, R_CHANGE.1, U2.23 (IO15)
MISO: D12.2, J4.P7 (DAT0), R8.1, TP6.TP, U1.2 (DO(IO1)), U2.27 (IO2)
MOSI: D11.2, J1.14, J4.P3 (CMD), R7.1, TP7.TP, U1.5 (DI(IO0)), U2.7 (IO7)
unnamed: J2.B5, R2-USB.1
unnamed: C1_BAT1.1, D2.1 (CATHODE), IC4.1 (VIN), IC4.3 (CE), Q1.2 (S)
unnamed: J2.A5, R2-USB1.2
unnamed: C4.1, D3.2 (A), D4.1 (K)
unnamed: CHG_LED.C, R1_BAT.1
unnamed: MCP73831.1 (STAT), R1_BAT.2
unnamed: MCP73831.5 (PROG), R2_BAT.2
unnamed: EPD_C12.2, J1.24
unnamed: C_DELAY.1, IC1.5 (CT)
unnamed: D7.1 (CATHODE), R_CAPACITOR.1
unnamed: EPD_C8.2, J1.20
unnamed: D2.2 (ANODE), Q1.1 (G), R1_PWRUSB.2
unnamed: EPD_C10.2, J1.22
unnamed: EPD_C7.2, J1.19
unnamed: EPD_C6.2, J1.18
unnamed: EPD_C1.2, J1.4
unnamed: EPD_C2.2, J1.5
PREVGH: D5.1 (K), EPD_C9.2, J1.21
PREVGL: D4.2 (A), EPD_C11.2, J1.23
RESE: J1.3, Q3.2 (S), R3.2
RESE': R2.2, R3.1, SJ1.2
RESET: C5.1, IC1.1 (VOUT), RESET_BUTTON.3, RESET_BUTTON.4, R_RESET.1, U2.3 (EN)
RTC_RST: U2.16 (IO18), U3.4 (!RST)
RX: TP2.TP, U2.24 (RXD0/GPIO17)
SCK: D10.2, J1.13, J4.P5 (CLK), R6.1, TP8.TP, U1.6 (CLK), U2.6 (IO6)
SCL: J3.4, R2-PINH.1, SENSOR2.4 (SCK), U2.20 (IO22), U3.16 (SCL), U4.7 (SCL)
SDA: J3.3, R1_PINH.1, SENSOR2.3 (SDI), U2.19 (IO21), U3.15 (SDA), U4.8 (SDA)
SRC: C4.2, D5.2 (A), L1.1, Q3.3 (D)
SS_SD: D8.2, J4.P2 (CD/DAT3), R10.1, U2.4 (IO4)
TX: TP1.TP, U2.25 (TXD0/GPIO16)
USB_D+: D1.1 (I/O1_1), U2.14 (IO13)
USB_D-: D1.3 (I/O2_1), U2.13 (IO12)
VBAT: C2_BAT.1, MCP73831.3 (VBAT), Q1.3 (D), TP3.TP, U4.2 (CELL), U4.3 (VDD)
VBUS: C1_BAT.1, C4_USB.1, C5_USB.1, CHG_LED.A, D1.5 (VBUS), MCP73831.4 (VIN), PFMF.050.1.2, TP14.TP
VRTC: C8.1, C10_SUPERCAP.1, R_CAPACITOR.2, U3.14 (VBAT)
VUSB: J2.A4, J2.A9, J2.B4, J2.B9, PFMF.050.1.1

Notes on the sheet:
USB C connector & ESD protection
LDO Voltage Regulator
DMG2305UX-7
SD0805S020S1R0
SD Card
Display Type Selector
E-Paper Drive Circuit
Li-Po Battery Charging Controller
ESP32 C6
E-Paper Display Header
EPD Power
Environmental Sensor BME688
BME688
Battery Charge Level
Voltage Supervisor + Reset & Boot / IO Button
RTC Module DS3231SN
Test Pads
Qwiic / Stemma QT
SPI ESD Protection Lines
External NOR Flash 64MB
OpenBook Schematic
drawn by: Georgiana Ilie

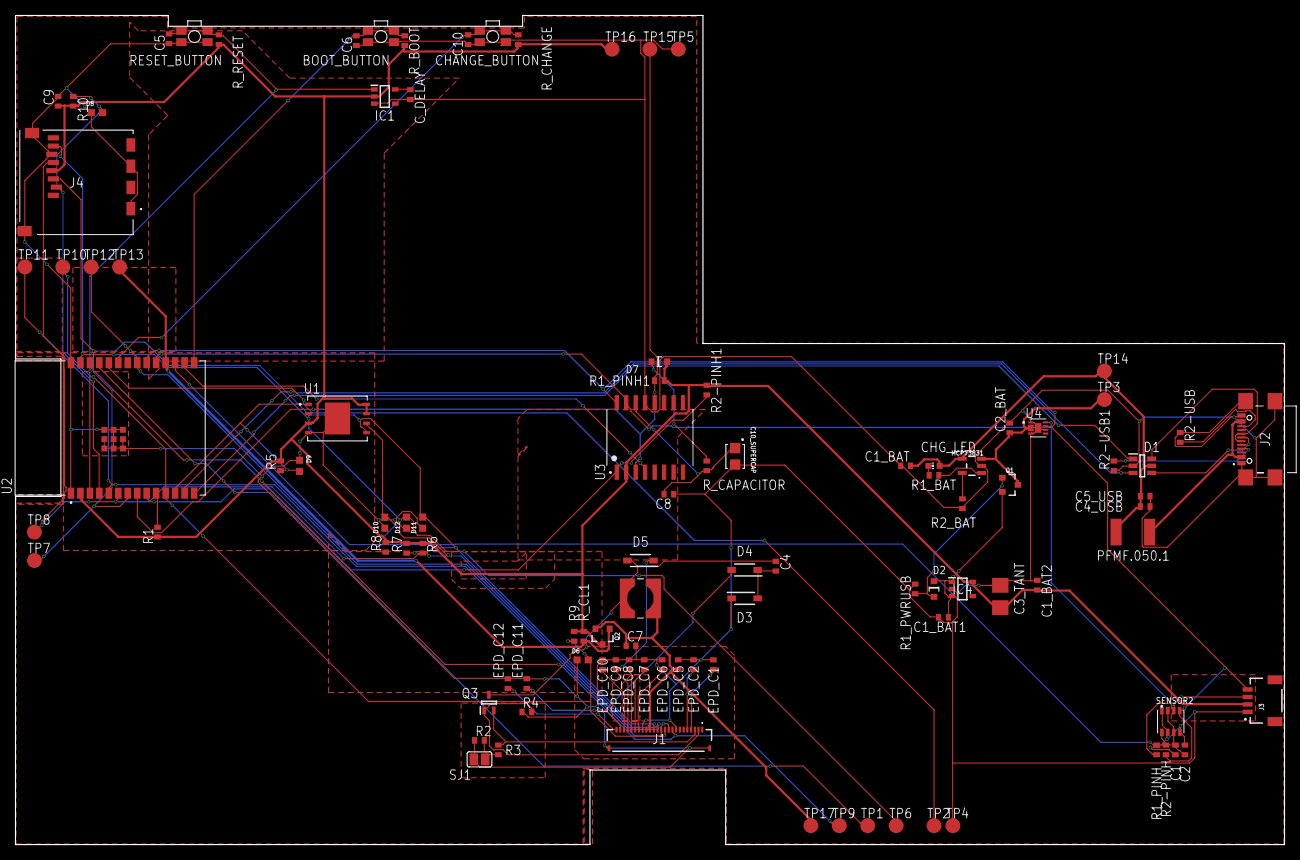
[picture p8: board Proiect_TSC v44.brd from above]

Board: 2 copper layers, 170.2 x 111.2 mm, 103 parts (0 on the bottom side), 56 nets.

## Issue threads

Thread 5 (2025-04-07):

Sugestii pentru redactare README.md

DariusIuga, 2025-04-07:
- Pune BOM si alocarea pinilor sub forma de tabel in Markdown.
- Pune cateva dintre pozele din Images in readme.
- Redacteaza scrisul ca sa fie mai usor de citit: Pune fiecare subtitlu ca header si adauga bullet points la *Functionalitate Hardware* si la *Informatii suplimentare*.
- Ar fi bine sa scrii putin si despre pasii de implementare si problemele intampinate (daca sunt).

georgianailie109, 2025-04-14:
finished

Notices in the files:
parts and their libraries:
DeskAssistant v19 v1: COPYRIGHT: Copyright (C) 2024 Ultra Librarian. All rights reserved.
